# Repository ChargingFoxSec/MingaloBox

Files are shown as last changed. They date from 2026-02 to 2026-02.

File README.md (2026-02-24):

# Mingalobox

Mingalobox is a **wireless Hitbox / arcade-style game controller** project built around **nRF52840 + RP2040** (controller + USB dongle), with RP2040 running GP2040 firmware.

> For me, this is a milestone—both a summary of what I’ve accomplished so far and a new challenge. As a fighting game enthusiast, it’s rare to be able to build a device that truly meets my own expectations. I’ve also really enjoyed learning in a new domain and working through problems along the way.

This repository contains:

- `hardware/`: schematics/PCB/BOM/Gerbers and enclosure models.
- `firmware/`: nRF52840 wireless link firmware prototype based on **nRF Connect SDK (NCS) / Zephyr** Gazell samples (device + host). This part is under `LicenseRef-Nordic-5-Clause` and includes restrictions (for example, “Nordic IC only”).

> Note: `firmware/` currently focuses on validating the nRF52840 Gazell link. The RP2040 side is expected to run third-party GP2040(/GP2040-CE) firmware (not included in this repo).

## System Architecture (Target)

Wireless mode:

`nRF52840 transmitter (controller)` → `nRF52840 receiver (dongle)` → `Waveshare RP2040-Zero (GP2040 firmware)` → `PC / PS4 / PS5, etc.`

Wired mode:

- Optionally solder a **Raspberry Pi Pico (RP2040)** onto the controller PCB and flash GP2040, then the controller can be used standalone as a **wired** device (no dongle required).

## Repository Layout

- `firmware/controller/`: Gazell **Device** role (controller-side prototype)
- `firmware/dongle/`: Gazell **Host** role (dongle-side prototype)
- `hardware/controller/`: controller PCB/schematics/BOM/Gerbers
- `hardware/dongle/`: dongle PCB/schematics/BOM/Gerbers + 3D enclosure models

## Firmware: Build & Flash (NCS / Zephyr)

### Prerequisites

You need a working **Zephyr/NCS** environment and `west`.

#### About the “west workspace”

`west` is Zephyr/NCS’ workspace and build tool. Typically you create an NCS **west workspace** (containing `zephyr/`, `nrf/`, `nrfxlib/`, etc.), then build this repo’s `firmware/*` apps inside that workspace.

This repository itself is **not** a full west workspace (no `west.yml` / `.west/` at the repo root). Recommended: place this repo somewhere inside your existing NCS workspace, or build it as an external application from the workspace.

### Build

Example for `nrf52840dk_nrf52840` (nRF52840 DK). `sample.yaml` also lists `nrf52dk_nrf52832` and `nrf52833dk_nrf52833`.

```bash
west build -b nrf52840dk_nrf52840 -s firmware/controller -d build/controller
west build -b nrf52840dk_nrf52840 -s firmware/dongle     -d build/dongle
```

### Flash

```bash
west flash -d build/controller
west flash -d build/dongle
```

### Notes

- These samples exchange 1-byte payloads over Gazell and use the DK buttons/LEDs (`dk_buttons_and_leds`) for a quick demo.
- To complete the full pipeline “buttons → wireless → RP2040(GP2040) → USB HID”, additional integration is required on both controller/dongle sides (real button inputs and the interface/protocol to RP2040).
- `gpio_output_voltage_setup_3v3()` in both `main.c` writes UICR `REGOUT0` and triggers a reset (non-volatile configuration write). Use with care on production hardware.

## Hardware

Hardware files live in `hardware/`:

- Key parts (current version):
  - nRF52840: Ebyte `E73-2G4M08S1C` module (ceramic antenna)
  - Controller RP2040: `Raspberry Pi Pico` (optional, for wired GP2040 mode)
  - Dongle RP2040: `Waveshare RP2040-Zero` (USB side running GP2040)
- `*/sch/*.json`, `*/pcb/*.json`: schematic/PCB source files (editor depends on the export source)
- `*/gerber/*.zip`: Gerber packages
- `*/bom/*.xlsx`: BOMs
- `hardware/dongle/3DShellModel/*.stl`: dongle enclosure models

## License

- Unless stated otherwise, author-written content in this repository is licensed under `Apache-2.0` (see `LICENSE` and `NOTICE`).
- `firmware/controller/` and `firmware/dongle/` include Nordic Semiconductor ASA sample/derived code and are marked with `SPDX-License-Identifier: LicenseRef-Nordic-5-Clause` (see `LICENSES/LicenseRef-Nordic-5-Clause.txt`).
  - This Nordic license includes restrictions (for example “Nordic IC only”), so those parts are **not** licensed under `Apache-2.0`.

## Feedback

Issues are welcome (no guarantee of response time or acceptance). For PRs, please open an issue first to align on scope/approach.

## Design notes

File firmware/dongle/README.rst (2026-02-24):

.. _gzll_ack_payload_host:

Gazell ACK Payload Host
#######################

.. contents::
   :local:
   :depth: 2

This sample shows the Host role for basic Gazell communication.
As a single sample, the Host receives packets from the Device and transmits acknowledgements with the payload.
Follow the instructions and use the files from this page, and the :ref:`gzll_ack_payload_device` sample.

Requirements
************

.. note::
   Follow the steps from and include the :ref:`gzll_ack_payload_device` sample with this sample.

.. gzll_ack_sample_requirements_start

The sample supports the following development kits:

.. table-from-sample-yaml::

You can use any two of the development kits listed above and mix different development kits.

.. gzll_ack_sample_requirements_end

.. gzll_ack_sample_overview_start

Overview
********

The sample uses the :ref:`gzll` library to exchange packets with payload in two directions.
It consists of two applications, a Device and a Host.

* Device
   A Device sends a packet and adds a new packet to the TX queue every time it receives an ACK from Host.
   Before adding a packet to the TX queue, the contents of the buttons are copied to the first payload byte.
   When the Device receives an ACK, the contents of the first payload byte of the ACK are output to the LEDs.

* Host
   A Host listens for a packet and sends an ACK when it has received the packet.
   The contents of the first payload byte of the received packet is output to LEDs.
   The contents of buttons are sent in the first payload byte of the ACK packet.

.. msc::
   hscale = "1.3";
   Device,Host;
   Host note Host      [label="Add button contents to the first payload byte"];
   Host note Host      [label="Add new packet to TX FIFO"];
   Device note Device  [label="Copy button contents to the first payload byte"],Host note Host [label="Listen for a packet"];
   Device note Device  [label="Add new packet to TX FIFO"];
   Device=>Host        [label="Packet"];
   Host note Host      [label="Send ACK"];
   Host=>Device        [label="ACK"];
   Host note Host      [label="Output first payload byte of packet to LEDs"];
   Device note Device  [label="Output first payload byte of ACK to LEDs"],Host note Host [label="Add button contents to the first payload byte"];
   Device note Device  [label="Copy button contents to the first payload byte"],Host note Host [label="Add new packet to TX FIFO"];
   Device note Device  [label="Add new packet to TX FIFO"];
   Device=>Host        [label="Packet"];

The Device transmits packets with its buttons state and the Host acknowledges all successfully received packets from the Device and adds its buttons state in the ACK packets it transmits.
Both devices display the peer's buttons state on their LEDs
You can use this sample to enable simple, bidirectional data exchange over the Gazell protocol between two devices.

.. gzll_ack_sample_overview_end

.. gzll_ack_sample_ui_start

User interface
**************

LED 1-4:
   Indicate that packets are received.
   An LED is turned off when the corresponding button is pressed on the other kit.

Button 1-4:
   The button pressed state bitmask is sent to the other kit.
   A button pressed is sent as 0 and a button released is sent as 1.

.. gzll_ack_sample_ui_end

.. gzll_ack_sample_building_start

Building and running
********************

The Device sample is under :file:`samples/gazell/gzll_ack_payload_device` in the |NCS| folder structure.
The Host sample is under :file:`samples/gazell/gzll_ack_payload_host` in the |NCS| folder structure.

See :ref:`building` and :ref:`programming` for information about how to build and program the application, respectively.

Testing
=======

After programming the Device sample on one of the development kits and the Host sample on the other kit, test them by performing the following steps:

1. Power on both kits.
#. Observe that all the LEDs light up on both kits.
#. Press **Button 1** for the Device sample.
   Observe that the Host sample turns off **LED 1** on the other kit.
#. Press **Button 2** for the Host sample.
   Observe that the Device sample turns off **LED 2** on the other kit.
#. Optionally, connect to the kits with a terminal emulator (for example, nRF Connect Serial Terminal).
   See :ref:`test_and_optimize` for the required settings and steps.
#. Observe the logging output for both kits.

.. gzll_ack_sample_building_end

.. gzll_ack_sample_dependencies_start

Dependencies
************

This sample uses the following |NCS| libraries:

* :ref:`gzll_glue`
* :ref:`dk_buttons_and_leds_readme`

It uses the following :ref:`nrfxlib` library:

* :ref:`nrfxlib:gzll`

It uses the following Zephyr libraries:

* ``include/zephyr/types.h``
* :ref:`zephyr:logging_api`
* :ref:`zephyr:kernel_api`:

  * ``include/kernel.h``
  * ``include/irq.h``

.. gzll_ack_sample_dependencies_end

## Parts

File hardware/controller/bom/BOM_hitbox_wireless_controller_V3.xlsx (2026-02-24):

No. | Quantity | Comment | Designator | Footprint | Value | Manufacturer Part | Manufacturer | Supplier Part | Supplier | LCSC Stock | LCSC Price | Category | JLCPCB Price
1 | 2 | 10uF | C1,C2 | C0805
2 | 1 | 0.1uF | C3 | C0805
3 | 6 | 22uF | C4,C5,C6,C7,C8,C9 | C0805
4 | 4 | 0.1uF | C18,C19,C20,C21 | C0603
5 | 1 | NC | C22 | C0603
6 | 1 | XH-2AW_C2908611 | CN1 | CONN-TH_XH-2AW_C2908611 |  | XH-2AW | HCTL(华灿天禄) | C2908611 | LCSC | 1783 | 0.0791 |  | 0.0791
7 | 2 | HDR-F-2.54_1x20 | H1,H2 | HDR-F-2.54_1X20 |  |  |  | C50984 | LCSC | 0 | 1.2321 |  | 1.232
8 | 2 | HDR-F-2.54_1x4 | H3,H6 | HDR-F-2.54_1X4 |  |  |  | C225501 | LCSC | 0 | 0.6347 |  | 0.635
9 | 1 | X6521WR-2×18H-C30D60 | H4 | HDR-TH_36P-P2.54-H-M-R2-C18-S2.54 |  | X6521WR-2x18H-C60D30 | XKB Connection(中国星坤) | C725930 | LCSC | 496 | 3.25 |  | 3.25
10 | 4 | HDR-M-2.54_1x2 | J1,J2,J3,J4 | HDR-M-2.54_1X2 |  |  |  | C124375 | LCSC | 4266 | 0.1674 |  | 0.167
11 | 1 | 1uH | L1 | IND-SMD_L7.0-W6.6 |  | FXL0630-1R0-M | cjiang(长江微电) | C167216 | LCSC | 12954 | 0.7001 |  | 0.7
12 | 8 | LED-0805_G | LED1,LED2,LED3,LED4,LED6,LED7,LED8,LED9 | LED0805_GREEN |  | NCD0805G1 | 国星光电 | C84260 |  | 45262 | 0.1359 |  | 0.136
13 | 1 | 2R | R1 | R0805
14 | 2 | 5.1K | R2,R3 | R0805
15 | 4 | 1K | R4,R5,R6,R7 | R0805
16 | 1 | 0.5R | R8 | R0805
17 | 1 | 10K | R9 | R0805
18 | 5 | 10K | R12,R13,R14,R15,R16 | R0603
19 | 1 | SK12D07VG4 | SW1 | SW-TH_SK12D07VG4 |  | SK12D07VG4 | SHOU HAN(首韩) | C393937 | LCSC | 3365 | 0.1622 |  | 0.162
20 | 1 | TS-1093C-A9B2-D1 | SW2 | SW-TH_TS-1093C-A9B3-D1 |  | TS-1093C-A9B2-D1 | Yuandi(元迪) | C2682920 | LCSC | 195 | 0.3842 |  | 0.384
21 | 1 | TS-1101-C-W | SW3 | SW-SMD_L6.0-W3.3-LS8.0 |  | TS-1101-C-W | XKB Connectivity(中国星坤) | C318938 | LCSC | 7791 | 0.2689 |  | 0.269
22 | 1 | IP5306 | U1 | ESOP-8_L4.9-W3.9-P1.27-LS6.0-BL-EP |  | IP5306 | INJOINIC(英集芯) | C181692 | LCSC | 10987 | 1.7456 |  | 1.746
23 | 1 | E73-2G4M08S1C | U4 | WIRELM-SMD_E73-2G4M08S1C |  | E73-2G4M08S1C | EBYTE(亿佰特) | C356849 | LCSC | 790 | 50.3 |  | 50.3
24 | 1 | TYPE-C 6P(073) | USB1 | TYPE-C-SMD_TYPE-C-6P |  | TYPE-C 6P(073) | SHOU HAN(首韩) | C668623 | LCSC | 19187 | 0.2436 |  | 0.244
25 | 1 | AF 90° WJDG | USB2 | USB-A-TH_AF-WJDG |  | AF 90° WJDG | SHOU HAN(首韩) | C456018 | LCSC | 6117 | 0.3096 |  | 0.31

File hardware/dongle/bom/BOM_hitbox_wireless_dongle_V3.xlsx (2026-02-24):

No. | Quantity | Comment | Designator | Footprint | Value | Manufacturer Part | Manufacturer | Supplier Part | Supplier | LCSC Stock | LCSC Price | Category | JLCPCB Price
1 | 4 | 0.1uF | C1,C2,C3,C4 | C0603
2 | 1 | NC | C10 | C0603
3 | 1 | HDR-F-2.54_1x4 | H6 | HDR-F-2.54_1X4 |  |  |  | C225501 | LCSC | 0 | 0.6347 |  | 0.635
4 | 4 | LED-0805_G | LED1,LED2,LED3,LED4 | LED0805_GREEN |  | NCD0805G1 | 国星光电 | C84260 |  | 45262 | 0.1359 |  | 0.136
5 | 5 | 10K | R1,R2,R3,R4,R5 | R0603
6 | 1 | TS-1109S-B-H | SW1 | SW-SMD_4P-L4.5-W4.5-P3.00-LS6.8 |  | TS-1109S-B-H | XKB Connectivity(中国星坤) | C480321 | LCSC | 379 | 0.2096 |  | 0.21
7 | 1 | E73-2G4M08S1C | U1 | WIRELM-SMD_E73-2G4M08S1C |  | E73-2G4M08S1C | EBYTE(亿佰特) | C356849 | LCSC | 790 | 50.3 |  | 50.3
8 | 1 | RP2040-CORE-A | U2 | RP2040-CORE-A |  | X6511WV-25H-C60D30 | XKB Connection(中国星坤) | C725957 | LCSC | 1342 | 2.6 |  | 2.6
9 | 1 | AM90 | USB1 | USB-AM-TH_AM90 |  | AM90 | SHOU HAN(首韩) | C404965 | LCSC | 4139 | 0.4259 |  | 0.426
10 | 1 | USB-234-BCW | USB2 | USB-A-SMD_USB-234-BCW |  | USB-234-BCW | XUNPU(讯普) | C720528 | LCSC | 2701 | 0.6886 |  | 0.689

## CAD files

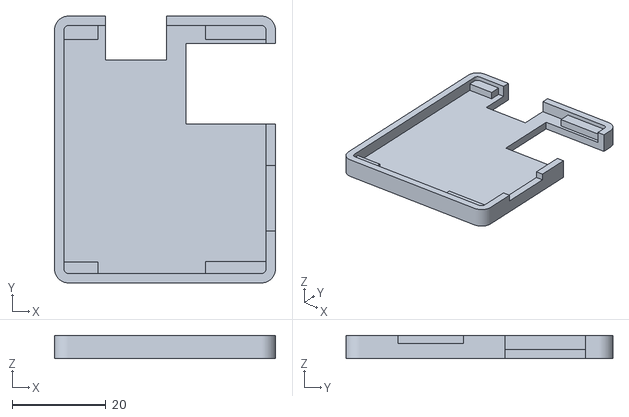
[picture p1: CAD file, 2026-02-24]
hardware/dongle/3DShellModel/3DShell_Receiver_bottom_V3.stl
47.1 x 56.9 x 5.00

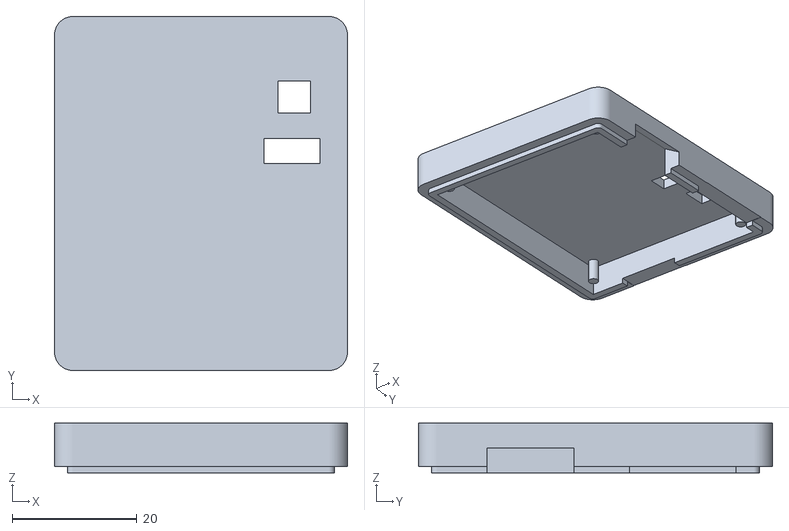
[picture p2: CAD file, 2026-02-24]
hardware/dongle/3DShellModel/3DShell_Receiver_top_V3.stl
47.1 x 56.9 x 8.00

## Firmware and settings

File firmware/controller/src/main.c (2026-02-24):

/*
 * Copyright (c) 2021 Nordic Semiconductor ASA
 *
 * SPDX-License-Identifier: LicenseRef-Nordic-5-Clause
 */

#include <zephyr/kernel.h>
#include <nrf_gzll.h>
#include <gzll_glue.h>
#include <dk_buttons_and_leds.h>

#include <zephyr/logging/log.h>

LOG_MODULE_REGISTER(app);

/* Pipe 0 is used in this example. */
#define PIPE_NUMBER 0

/* 1-byte payload length is used when transmitting. */
#define TX_PAYLOAD_LENGTH 1

/* Maximum number of transmission attempts */
#define MAX_TX_ATTEMPTS 100

/* Gazell Link Layer TX result structure */
struct gzll_tx_result {
	bool success;
	uint32_t pipe;
	nrf_gzll_device_tx_info_t info;
};

/* Payload to send to Host. */
static uint8_t data_payload[TX_PAYLOAD_LENGTH];

/* Placeholder for received ACK payloads from Host. */
static uint8_t ack_payload[NRF_GZLL_CONST_MAX_PAYLOAD_LENGTH];

#ifdef CONFIG_GZLL_TX_STATISTICS
/* Struct containing transmission statistics. */
static nrf_gzll_tx_statistics_t statistics;
static nrf_gzll_tx_statistics_t statistics_2;
#endif

/* Gazell Link Layer TX result message queue */
K_MSGQ_DEFINE(gzll_msgq,
	      sizeof(struct gzll_tx_result),
	      1,
	      sizeof(uint32_t));

/* Main loop semaphore */
static K_SEM_DEFINE(main_sem, 0, 1);

static struct k_work gzll_work;

static void gzll_tx_result_handler(struct gzll_tx_result *tx_result);
static void gzll_work_handler(struct k_work *work);

/***************************************************************************
* 描  述 : 设置GPIO高电平时的输出电压为3.3V 
* 入  参 : 无 
* 返回值 : 无
**************************************************************************/
static void gpio_output_voltage_setup_3v3(void)
{
    //读取UICR_REGOUT0寄存器，判断当前GPIO输出电压设置的是不是3.3V，如果不是，设置成3.3V
    if ((NRF_UICR->REGOUT0 & UICR_REGOUT0_VOUT_Msk) !=
        (UICR_REGOUT0_VOUT_3V3 << UICR_REGOUT0_VOUT_Pos))
    {
        NRF_NVMC->CONFIG = NVMC_CONFIG_WEN_Wen;
        while (NRF_NVMC->READY == NVMC_READY_READY_Busy)
        {
        }

        NRF_UICR->REGOUT0 = (NRF_UICR->REGOUT0 & ~((uint32_t)UICR_REGOUT0_VOUT_Msk)) |
                            (UICR_REGOUT0_VOUT_3V3 << UICR_REGOUT0_VOUT_Pos);

        NRF_NVMC->CONFIG = NVMC_CONFIG_WEN_Ren;
        while (NRF_NVMC->READY == NVMC_READY_READY_Busy)
        {
        }

        //复位更新UICR寄存器
        NVIC_SystemReset();
    }
}

int main(void)
{
	gpio_output_voltage_setup_3v3();
	int err;
	bool result_value;

	k_work_init(&gzll_work, gzll_work_handler);

	err = dk_leds_init();
	if (err) {
		LOG_ERR("Cannot initialize LEDs (err: %d)", err);
		return 0;
	}

	err = dk_buttons_init(NULL);
	if (err) {
		LOG_ERR("Cannot initialize buttons (err: %d)", err);
		return 0;
	}

	/* Initialize Gazell Link Layer glue */
	result_value = gzll_glue_init();
	if (!result_value) {
		LOG_ERR("Cannot initialize GZLL glue code");
		return 0;
	}

	/* Initialize the Gazell Link Layer */
	result_value = nrf_gzll_init(NRF_GZLL_MODE_DEVICE);
	if (!result_value) {
		LOG_ERR("Cannot initialize GZLL");
		return 0;
	}

	nrf_gzll_set_max_tx_attempts(MAX_TX_ATTEMPTS);

#ifdef CONFIG_GZLL_TX_STATISTICS
	/* Turn on transmission statistics gathering. */
	result_value = nrf_gzll_tx_statistics_enable(&statistics);
	if (!result_value) {
		LOG_ERR("Cannot enable GZLL TX statistics");
		return 0;
	}
#endif

	data_payload[0] = ~dk_get_buttons();

	result_value = nrf_gzll_add_packet_to_tx_fifo(PIPE_NUMBER, data_payload, TX_PAYLOAD_LENGTH);
	if (!result_value) {
		LOG_ERR("Cannot add packet to GZLL TX FIFO");
		return 0;
	}

	result_value = nrf_gzll_enable();
	if (!result_value) {
		LOG_ERR("Cannot enable GZLL");
		return 0;
	}

	LOG_INF("heiheiheiGzll ack payload device example started.");

	while (true) {
		if (k_sem_take(&main_sem, K_FOREVER)) {
			continue;
		}

#ifdef CONFIG_GZLL_TX_STATISTICS
		if (statistics.packets_num >= 1000) {
			uint32_t key = irq_lock();

			statistics_2 = statistics;

			/* Reset statistics buffers. */
			nrf_gzll_reset_tx_statistics();

			irq_unlock(key);

			/* Print all transmission statistics. */
			LOG_INF("");
			LOG_INF("Total transmitted packets:   %4u",  statistics_2.packets_num);
			LOG_INF("Total transmission time-outs: %03u", statistics_2.timeouts_num);
			LOG_INF("");

			for (uint8_t i = 0; i < nrf_gzll_get_channel_table_size(); i++) {
				LOG_INF(
				"Channel %u: %03u packets transmitted, %03u transmissions failed.",
				i,
				statistics_2.channel_packets[i],
				statistics_2.channel_timeouts[i]);
			}
		}
#endif
	}
}

static void gzll_device_report_tx(bool success,
				  uint32_t pipe,
				  nrf_gzll_device_tx_info_t *tx_info)
{
	int err;
	struct gzll_tx_result tx_result;

	tx_result.success = success;
	tx_result.pipe = pipe;
	tx_result.info = *tx_info;
	err = k_msgq_put(&gzll_msgq, &tx_result, K_NO_WAIT);
	if (!err) {
		/* Get work handler to run */
		k_work_submit(&gzll_work);
	} else {
		LOG_ERR("Cannot put TX result to message queue");
	}
}

void nrf_gzll_device_tx_success(uint32_t pipe, nrf_gzll_device_tx_info_t tx_info)
{
	gzll_device_report_tx(true, pipe, &tx_info);
}

void nrf_gzll_device_tx_failed(uint32_t pipe, nrf_gzll_device_tx_info_t tx_info)
{
	gzll_device_report_tx(false, pipe, &tx_info);
}

void nrf_gzll_disabled(void)
{
}

void nrf_gzll_host_rx_data_ready(uint32_t pipe, nrf_gzll_host_rx_info_t rx_info)
{
}

static void gzll_work_handler(struct k_work *work)
{
	struct gzll_tx_result tx_result;

	/* Process message queue */
	while (!k_msgq_get(&gzll_msgq, &tx_result, K_NO_WAIT)) {
		gzll_tx_result_handler(&tx_result);
	}

	/* Get main loop to run */
	k_sem_give(&main_sem);
}

static void gzll_tx_result_handler(struct gzll_tx_result *tx_result)
{
	int err;
	bool result_value;
	uint32_t ack_payload_length = NRF_GZLL_CONST_MAX_PAYLOAD_LENGTH;

	if (tx_result->success) {
		if (tx_result->info.payload_received_in_ack) {
			/* Pop packet and write first byte of the payload to the GPIO port. */
			result_value = nrf_gzll_fetch_packet_from_rx_fifo(tx_result->pipe,
									  ack_payload,
									  &ack_payload_length);
			if (!result_value) {
				LOG_ERR("RX fifo error");
			} else if (ack_payload_length > 0) {
				err = dk_set_leds(ack_payload[0] & DK_ALL_LEDS_MSK);
				if (err) {
					LOG_ERR("Cannot output LEDs (err: %d)", err);
				}
			}
		}
	} else {
		LOG_ERR("Gazell transmission failed");
	}

	/* Load data payload into the TX queue. */
	data_payload[0] = ~dk_get_buttons();
	result_value = nrf_gzll_add_packet_to_tx_fifo(tx_result->pipe,
						      data_payload,
						      TX_PAYLOAD_LENGTH);
	if (!result_value) {
		LOG_ERR("TX fifo error");
	}
}
